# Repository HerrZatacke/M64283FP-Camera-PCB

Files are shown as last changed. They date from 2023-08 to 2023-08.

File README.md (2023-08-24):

# M64283FP Camera PCB

A PCB for mounting the M64283FP sensor to use it with a regular GameBoy Camera

With the revision from [24. Aug 2023](#24-aug-2023) it acts also as a good improvement against lightleaks when using the regular sensor ([Note this](#disclaimer)). 

This KiCad Project aims to replace the original GameBoy Camera Sensor PCB to allow using the alternative M64283FP sensor including accessing it's two extra pins `TADD` and `STRB`

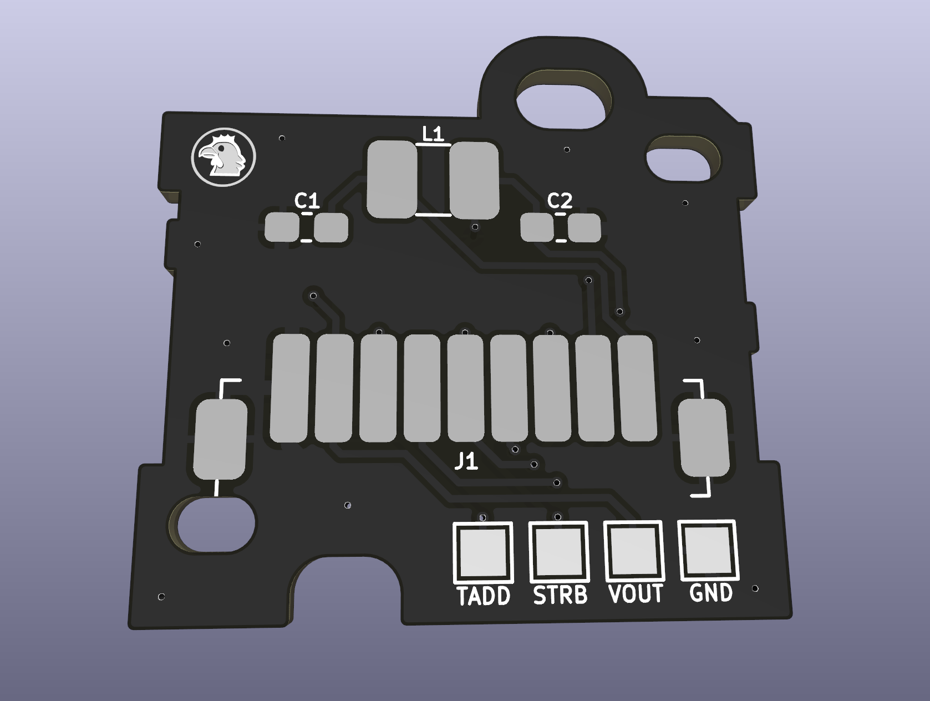
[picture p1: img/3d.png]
3D view


## License
[MIT](LICENSE)

## Revision History
### 24. Aug 2023
  * Added Solderpoints for GND and VOUT
  * Changed PCB Shape to prevent light leaking
  * Changed footprints to prevent
### [08. Aug 2023](https://github.com/HerrZatacke/M64283FP-Camera-PCB/tree/d5482509ec9628336e77a40f23f6922016d4d017)
  * Initial Version

## Disclaimer
Attempt all modifications at your own risk. All sensors are highly sensitive to excessive heat. SMD projects are not for beginners. Use common sense. 

## Links
- Thanks to [Raphaël Boichot](https://github.com/Raphael-Boichot/) for starting the project.
- Visit the [Game Boy Gamera Club Discord](https://discord.gg/C7WFJHG) for discussions.
- Mitsubishi [M64282FP Sensor Datasheet](https://pdf1.alldatasheet.com/datasheet-pdf/view/146598/MITSUBISHI/M64282FP.html) (original sensor)
- Mitsubishi [M64283FP Sensor Datasheet](https://pdf1.alldatasheet.com/datasheet-pdf/view/89637/MITSUBISHI/M64283FP.html) (replacement sensor)

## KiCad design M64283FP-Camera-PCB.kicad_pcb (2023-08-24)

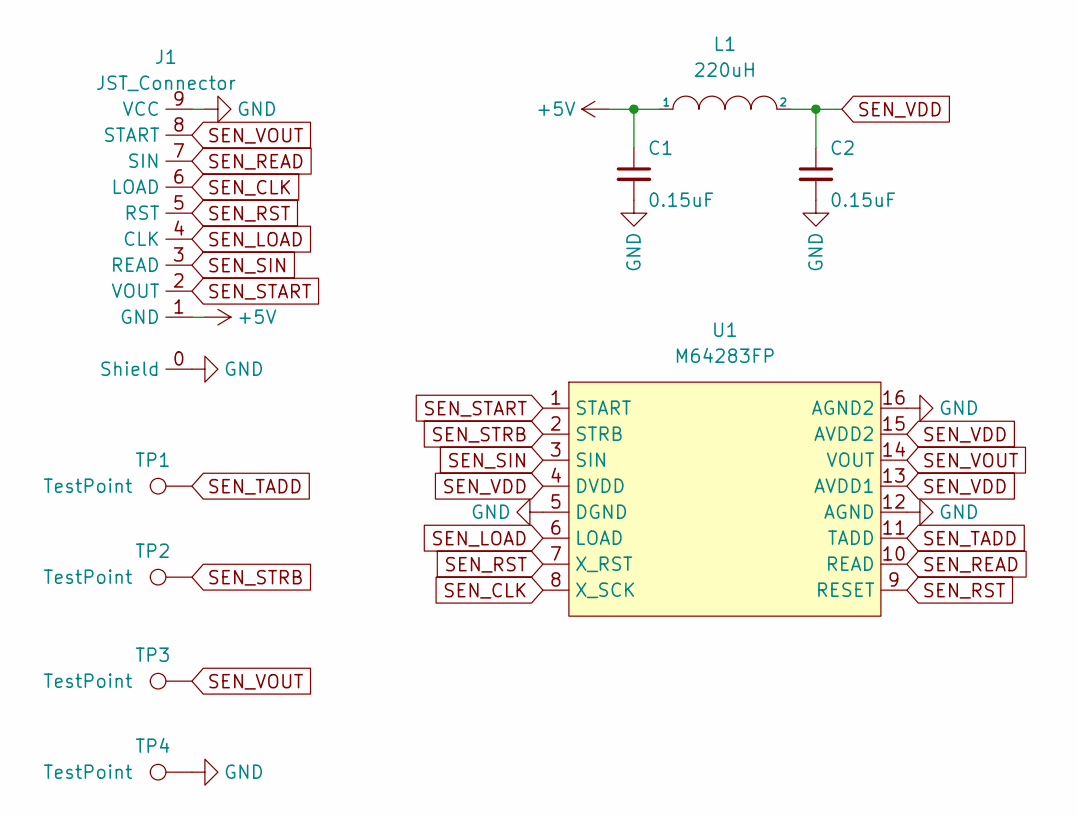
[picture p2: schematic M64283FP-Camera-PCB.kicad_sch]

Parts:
C1, C2: 0.15uF; 0603_HandSolder (LP)
J1: JST_Connector; JST Connector (LP)
L1: 220uH; 1210_HandSolder (LP)
TP1, TP2, TP3, TP4: TestPoint; TestPoint_Pad_1.5x1.5mm (LP)
U1: M64283FP; M6428xFP (LP)

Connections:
+5V: C1.1, J1.1 (GND), L1.1
GND: C1.2, C2.2, J1.0 (Shield), J1.9 (VCC), TP4.1, U1.5 (DGND), U1.12 (AGND), U1.16 (AGND2)
SEN_CLK: J1.6 (LOAD), U1.8 (X_SCK)
SEN_LOAD: J1.4 (CLK), U1.6 (LOAD)
SEN_READ: J1.7 (SIN), U1.10 (READ)
SEN_RST: J1.5 (RST), U1.7 (X_RST), U1.9 (RESET)
SEN_SIN: J1.3 (READ), U1.3 (SIN)
SEN_START: J1.2 (VOUT), U1.1 (START)
SEN_STRB: TP2.1, U1.2 (STRB)
SEN_TADD: TP1.1, U1.11 (TADD)
SEN_VDD: C2.1, L1.2, U1.4 (DVDD), U1.13 (AVDD1), U1.15 (AVDD2)
SEN_VOUT: J1.8 (START), TP3.1, U1.14 (VOUT)

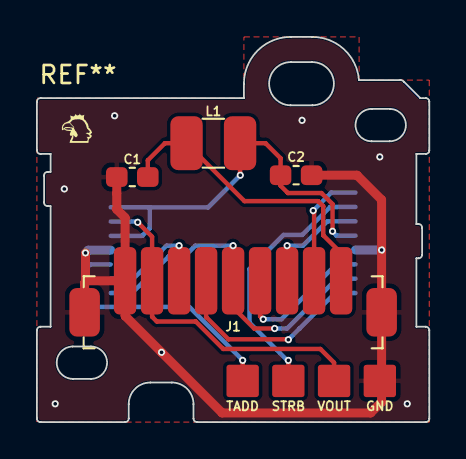
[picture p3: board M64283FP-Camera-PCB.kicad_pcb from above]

Board: 2 copper layers, 21.8 x 21.4 mm, 9 parts (1 on the bottom side), 12 nets.

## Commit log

2023-08-07 Initial project data
    [M64283FP-Camera-PCB.kicad_pcb, M64283FP-Camera-PCB.kicad_sch]
2023-08-07 Add preview image Optimize labels
    [M64283FP-Camera-PCB.kicad_pcb]
2023-08-24 Add LightProof (LP) footprints
2023-08-24 Update project with new footprints and PCB shape
    [M64283FP-Camera-PCB.kicad_pcb, M64283FP-Camera-PCB.kicad_sch]
2023-08-24 Add Lightproof testpoint
    [M64283FP-Camera-PCB.kicad_pcb, M64283FP-Camera-PCB.kicad_sch]
